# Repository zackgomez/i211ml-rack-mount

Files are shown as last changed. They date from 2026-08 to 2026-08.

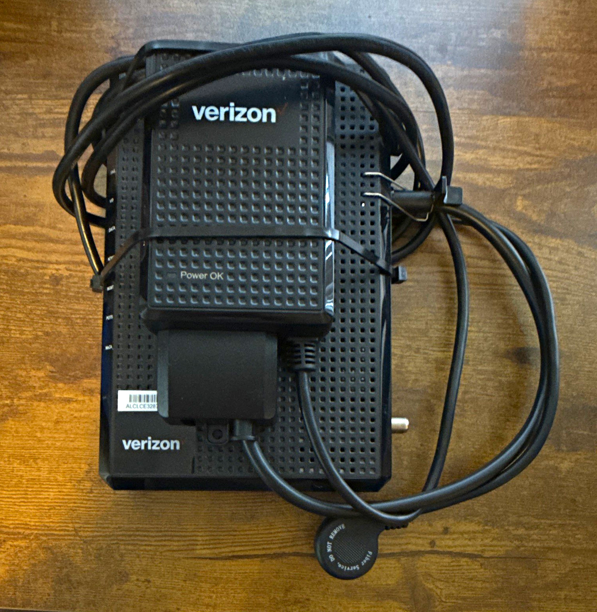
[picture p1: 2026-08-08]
references/ebay-power-brick.jpg

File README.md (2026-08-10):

# Verizon ONT I-211M-L — 19" Rack Mount

**Published**: https://www.printables.com/model/1806857-verizon-fios-i-211m-l-ont-power-brick-19-rack-moun
(CC BY 4.0). Installed and in service 2026-08-10 — ONT in the rack, on the UPS.

Design and print a 1U (or 2U) rack mount for the Verizon FiOS ONT (Alcatel-Lucent
I-211M-L) plus its inline power brick, so the ONT moves from the basement wall box
into the server rack. Fiber arrives as a stiff black drop, coiled/anchored in the
wall box's back pocket, terminating in a green SC/APC connector that plugs into the
ONT — so the move is unplug → re-route a couple feet → replug (or a longer G.657
SC/APC simplex patch cable if slack runs short).

## Device facts

Measured 2026-08-08 with soft tape (±2 mm) except items marked *calipers*.
The Alcatel manual claims 249 × 159 × 38 — trust the tape+calipers numbers below.

**ONT — Alcatel-Lucent I-211M-L** (P/N 3FE52343AKAA, our unit SN ALCLF4493816)
- 227 (x, tape) × 148 (y, *calipers*) × 33 mm (z, *calipers*)
- 45° chamfer on ALL edges, face width 10.5 mm (*calipers*) → ~7.4 mm legs;
  the LED bevel is one of them
- 4 rubber feet on the bottom, Ø11 × 3 tall (*calipers*): gaps measured from
  the chamfer edge, applying on both axes from each corner — LED-side pair
  1.5, port-side pair 20 (centers 14.4 / 32.9 from their corners). Also
  unmeasured mounting bosses, shorter than the feet — the cage floats the
  ONT on its feet so bosses hover
- Rear-face ports, z-centered on the connector face (*calipers*): coax F
  center 36 from the −x face; green SC/APC fiber plug outer edge 20 from the
  +x face (so the fiber lives near the outer wall's rear exit gap)
- Power input: 12 VDC / 2.5 A, keyed circular connector ("TELECOM EQUIPMENT DO NOT
  UNPLUG" collar), max draw 10.5 W — heat is a non-issue, token venting suffices

**Power brick — Verizon "Power OK" inline PSU**
- Body 124 (x) × 85 (y, max) × 44 mm (z) — *calipers*. The y sides are
  drafted, widest at the mid-height shell seam: 83.4 at the bottom face,
  85.0 at the seam, back in toward the chamfer edge (assumed 83.4 via a
  symmetric draft — TODO calipers)
- 6 mm chamfer around the top-face perimeter; vertical edges lightly rounded
  (~r2.5, eyeball); bottom face edges sharp
- Mounting tabs (wall-box rail hooks), bottom-flush, outer vertical corners
  moderately rounded (~r2.5). Wedge profile: max height at the root, sloping
  down to a flat run at min height ending at the tip:
  - body −x end (*calipers*): 18.2 x × 20.3 y, NOT centered — 24.4 off the
    bottom face's −y edge (24.4 + 20.3 + 38.7 closes the 83.4 bottom width
    exactly); wedge 3.8 → 8.2 mm, 4 mm flat
  - far (+x) END of the cord hump: 11 x × 12.5 y, centered on the shroud;
    wedge 3.3 → 7.0 mm, 3 mm flat
- Cord shroud on the +x end (strain relief locking the output cord): 38 beyond
  the body in x, 53 wide in y, bottom-flush, 6 mm margin (*calipers*) off the
  widest −y edge. Side profile: flat top 14 below the brick top (tape), knee
  curving down to a 22.3 mm tip face (*calipers*; traced 2026-08-08, photo in
  Scan inbox). TWO cords (both Ø6, *calipers*) exit the +x end:
  - body cord: leaves the body face toward +y (exact y pending calipers)
    through a strain relief stacked in +x — rect slab 2.5 × 15 × 15, then
    cylinder Ø15 × 12.5 — whose top sits at half the brick height (22), cord
    centerline z ≈ 14.5
  - output cord: off the shroud tip, −y side of the +x tab, cord top 4.8
    below the tip face's max z (centerline z ≈ 14.5 — matches the body cord)
  A half-spool greeble — an unpopulated cord exit ("cord hat") — sits +y of
  the tab on the tip face, its y/z mirroring the output cord across the tab
  (all *calipers*): shaft Ø8 × 6.7, lip Ø10 × 2, bore Ø6, cut at the axis
  z-plane — flat below, half-round above. Full x chain
  incl. tabs ≈ 184 mm; the strain relief reaches ≈ 15 further — keep the
  mount's +x face fully open.
- Port edge (one side): coax F, ground screw, 2× RJ11 POTS, 1× RJ45 GigE, power.
  POTS/MoCA unused — only GigE + power + fiber need routing
- Fiber: SC/APC under a hinged cover on the end opposite the coax
- LEDs (PWR BAT FAIL VID DATA NTWK MGMT POTS MoCA) on the beveled long edge —
  keep visible from the rack front
- Back: 3 keyhole slots (two upper, one lower-center) + 4 rubber feet

**Power brick** — Verizon inline PSU ("Power OK" LED on top), large; has a molded
mounting clip/bracket. Measure the actual unit — dims TBD.

- 1U usable height ≈ 44 mm; ONT lying flat is 38 mm → fits 1U, tight. 2U buys
  room for the brick standing on edge and lazier cable routing.
- 19" opening ≈ 450 mm; ONT flat takes 249 mm → ~200 mm left for the brick bay.

## Design direction

Two-piece screwed-together modular mount, same pattern as the UCG-Fiber mount that
already works well in this rack
(`../UCG-Fiber+PSU+19-inch+Modular+Rack+Mount/` — cage + PSU holder + keystone
passthrough with patch cables). The Print3DSteve Etsy design (central cage + two
ear wings, keystone cutout in one wing) confirms the same architecture at 1U.

Orientation (decided): ONT connector edge (coax, POTS, GigE, power, fiber cover)
faces the REAR of the rack — fiber and power dress off the back, out of sight.
LED bevel faces front. Eth handoff = short patch cable from the rear GigE port,
routed inside the mount, to a keystone jack in the front plate.

Ideas to carry over / decide:
- ONT hangs on printed keyhole posts (3 slots on its back) instead of a full cage —
  smallest modeling job, LEDs stay visible
- Keystone cutout in the front plate (one wing), patch cable inside the mount
- Brick pocket + zip-tie anchors; the brick's own clip may snap onto a printed rail
- Fiber: generous bend radius everywhere (≥30 mm) coming off the rear

## cad/

OpenSCAD, parametric. Shared design language across both mounts:
`wall` / `panel_t` / `shelf_t` = 4 — deliberately kept at 4 (each knob's
4→3 saves only ~8–14 cm³ and spends stiffness exactly at the load
paths: eave retention flex, rack-face flatness, zip-anchor webs).
`devices.scad` = reference solids of ONT + brick (fillet /
chamfer params still TODO-measure). `gauges.scad` = printable go/no-go gauges;
pre-rendered STLs in `cad/stl/`:

- `gauge-ont-cap.stl` — C-channel, slips over the ONT end, checks 148 × 33
- `gauge-ont-length.stl` — U-bar over the 227 length
- `gauge-brick-cap.stl` — C-channel over the brick end, checks 88 × 44
- `gauge-brick-length.stl` — U-bar over the 128 length

All gauges carry 0.5 mm/side clearance (`clear` in gauges.scad). Print flat face
down, no supports. Re-export:
`openscad -D 'part="ont_cap"' -o stl/gauge-ont-cap.stl gauges.scad`

Mount STL + preview regeneration (from `cad/`):

```
openscad --export-format=asciistl -o stl/mount-left-1u.stl mount-left.scad
openscad --export-format=asciistl -D 'panel_u=2' -o stl/mount-left-2u.stl mount-left.scad
openscad --export-format=asciistl -o stl/mount-right-1u.stl mount.scad
openscad -o mount-left-preview.png --imgsize=1600,1100 --viewall --autocenter \
    --camera=0,0,0,65,0,150,0 mount-left.scad   # -preview-rear.png: rz 150->30;
                                                # -2u-preview: add -D 'panel_u=2';
                                                # mount-right-render.png: same
                                                # camera on mount.scad
```

**ASA shrink protocol**: print gauges at 100%, in ASA, same profile as the final
mount. Fit = measurement + shrink verified together; snug/no-go = measure the gap
and adjust `clear` / final pocket clearances. Target for device bays in the real
mount: ~1.5–2 mm/side (tape error + shrink + easy insertion).

Rack-width shrink note: 0.5 % over the 465.1 mm ear-hole span is ~2.3 mm — the
center-cage + two-wings + slotted joints architecture absorbs this; never print
the full 19" width as one piece.

## mount.scad — right half (ONT cage)

UCG-Fiber-style module, panel printed flat on the bed, no supports; 1U
primary (`panel_u`, 2 still renders). Test print v1 (2026-08-08, 1U,
fast ASA): bay width spot-on (227 device / 230 bay confirmed), eave
friction at +0.2 squeeze overly tight → now −0.1 (clearance);
`eave_squeeze` is the tuning knob. Geometry is authored as a left and
mirrored via `right_half = true` so the cage sits rack-RIGHT. The ONT
rides on its feet (solid pads in the hex field, bosses hover); retention
= side eaves + front brow hugging the chamfered edges, brick-cage style:
both side walls run the full bay depth (the inner one continues 4 thick
past the flange) with full-length eaves and the low eave-derived ceiling
(`wall_top = eave_y + eave_depth + 3`; the flange keeps full panel
height for the joint, the brow is panel-face material). The rear is
fully open — fiber, coax, and cords all dress off the back. Each wall
carries the same rounded elongated-hex windows as the brick cage (outer
wall two, inner wall one behind the solid joint span, z-aligned so the
cutouts read through the cage). Joint hardware: M5×16 button heads,
inset Ø10.8 × 3 into the flange's bay-side face (ISO 7380 head 9.5 ×
2.75 vs 1.5 bay clearance), nuts in the left piece's hex pockets.
Roundings match mount-left: panel outer corners r4, cage top-rear r8,
wall edges r2, flange top-rear r6, shelf rear r6.

## mount-left.scad — left half (brick enclosure)

217.6 wide, authored directly as a left; 1U primary (`panel_u`, 2 still
renders — see the variant paragraph below for how the 44-tall brick fits
a 1U panel). The brick lies flat on a hex-vented shelf, long axis along
rack DEPTH:
wall-box tab end forward, cord/shroud end out the fully open rear (both
cords + strain relief dress off the back). The bay sits OUTBOARD, just
inboard of the rack ear, so the brick's weight hangs next to the mounting
hardware — the cage stops 30 from the panel edge (the UCG mount runs 23
and clears this rack's posts; `ear_clear`). The floor plane spans only
the cage. The brick slides in from the rear: side eaves grab the 6 mm
top-perimeter chamfer (same `eave_squeeze` knob, −0.1), a front brow
grabs the front-top chamfer, and the −x tab passes through a slot in the
front wall — its tip rides to 2 from the panel FRONT face (the slot
pockets into the panel's back, keeping the front wall thin) — with a
hold-down bar riding 0.5 over its flat tip. Two
zip-tie slots behind the body anchor the AC cord so tugs land on the
mount, not the brick. Joint flange is 10 thick: M5 holes match mount.scad
(y = panel_h/2, z 20/48); hex nut pockets 8.2 across flats (UCG pockets
measure ~8.1 and press-fit on this printer), 6 deep over a 4 web — an
M5×16 tip lands flush. Two UCG-style gusset ramps brace the flange, one
near each panel edge and inset 6 in y — full 64 depth at the flange, free
edge a concave quarter-circle fillet running out to the panel at x=70.
Rounded corners: panel outer corners r4 (sized to keep the ear-slot web),
cage top-rear r8 across walls + eaves, cage outer edges r2 (wall
top-outer along z, rear verticals), flange rear corners r6 (tangent to
the ramps), shelf rear r6, keystone boss r3. Keystone slot at x = 52
(joint side), y = panel_h/2, face front, latch DOWN, jack in from the
rear: geometry measured off the UCG "Shelf Keystone x6" left module —
no tuned lip; the teeth wedge against tapered clamp faces (hook side
6.35→12.15 over 4.9 deep, latch side 45° 10.15→12.15), 24.3 × 15.0
cavity, and a rear plate whose 19.8 window guides the jack — cut into a
9.5-thick boss on the panel rear. Rack ear ovals 14 × 7 (UCG-style
horizontal play). Low eave-derived ceiling: walls and eaves stop 3 past
the eave slope (the brick's chamfered top stands ~2 proud; the brow's
45° underside runs exactly to the wall top). Material pass: each side
wall carries two elongated-hex windows (45° pointed ends print
bridge-free, corners r4, 8 rib between, rails tied to the
shelf/eave/brick-face/rear-round lines); the front wall is a windowed
frame — three through-pockets behind the panel, two flanking the tab
housing and one over it, keeping the full-perimeter brick stop, the
slot's keying walls + hold-down bar, and the brow foundation.

At 1U — the primary — the 44-tall brick beats the 43.65 panel only by
poaching inter-U slack: the brick tops out exactly at the panel's top
edge (~2.55 under the UCG mount above, whose rear structure starts 1.75
above its own panel edge, measured from its STL), and the floor + walls
hang 4.35 into the U below — empty in this rack — tucked behind the
panel face so nothing shows under the panel from the front. At 1U the
keystone shifts to x = 60 and the gusset runout shortens to x = 44 to
coexist; eaves, brow, tab slot, and joint holes (panel_h/2 pairs with
the right piece at 1U) all re-derive.

## Next steps

1. Caliper the foot center inset from the LED/port edges (est. 8 in
   devices.scad) + body cord y (`cordA_y`)
2. Reprint both pieces at 1U with the material pass + joint insets:
   right verifies eave feel + foot pads + button-head seating; left
   verifies bay/tab/eave fit after the brick-model correction (its test
   v1 2026-08-09: keystone perfect, rack + joint hardware fit well)
3. The physical move (unplug SC/APC, unmount wall box, re-route, replug)

## references/

- `ebay-ont-i211ml-1.jpg` — ¾ view, port edge + vented top
- `ebay-ont-i211ml-2.jpg` — spec label close-up (12VDC 2.5A, P/N, FCC)
- `ebay-ont-i211ml-3.jpg` — port edge straight on (coax, POTS×2, GigE, power, fiber cover)
- `ebay-ont-i211ml-4.jpg` — top face angled, LED labels
- `ebay-ont-i211ml-5.jpg` — front face portrait (Frontier branding, LED edge)
- `ebay-ont-i211ml-6.jpg` — back: 3 keyhole slots, feet, label
- `ebay-power-brick.jpg` — Verizon "Power OK" inline PSU strapped to a G-211M-C (brick style reference)
- `etsy-g211mc-*.png` — Print3DSteve 1U mount for the *G-211M-C* (different ONT, same
  architecture: center cage, two ear wings, keystone cutout)

## Links

- eBay ONT listing (photo source): https://www.ebay.com/itm/303900171619
- eBay brick listing (photo source): https://www.ebay.com/itm/358831177634
- Etsy G-211M-C 1U mount ($83, wrong model): https://www.etsy.com/listing/4328277623
- Print3DSteve also made an I-211M-L variant (Etsy, search their shop):
  https://br.pinterest.com/pin/155303888119943946/
- Only free I-211M-L print (Leviton SMC bracket, not rack):
  https://www.printables.com/model/396377 / https://www.thingiverse.com/thing:5145029
- Physical specs source (Alcatel-Lucent 7302 manual p.1042–1043):
  https://www.manualslib.com/manual/1575417/Alcatel-Lucent-7302.html?page=1042

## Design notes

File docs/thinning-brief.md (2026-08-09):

# Thinning brief — material/print-time pass

You are the third instance on this two-piece 19" rack mount (Verizon ONT
I-211M-L + power brick). Both halves are designed, test-printed once, and
fit-verified. Your mission is plastic and print time, in three stages, in
this order:

1. **Brick cage walls** (`cad/mount-left.scad`): hollow out the wall
   centers — big cutouts through the side walls' free spans, with
   aesthetic corner rounding on the interior (cutout) edges. The panel,
   shelf, front wall, flange, ramps, and keystone boss are NOT in scope
   yet. Also queued in this file, Zack-approved: reduce the front
   tab-seat wall to posts (it must keep: the forward stop for the brick
   face, the tab slot's side keying + hold-down bar over the tab's flat
   tip, and the brow's foundation — "wall with big windows" more than
   freestanding pins).
2. **Discussion**: the primary thickness dimension. `wall = 4`,
   `panel_t = 4`, `shelf_t = 4` are shared design language across BOTH
   pieces. Thinning any of them is a cross-piece change — bring options
   and tradeoffs (stiffness, joint meat, print time deltas) to Zack
   in-terminal, and coordinate with the right-piece session before
   changing shared numbers.
3. **ONT portion** (`cad/mount.scad`): same hollowing treatment. This
   file is owned by the coordinator session ("Design 1U enclosure for
   Verizon ONT relocation") — announce intent via SendMessage before
   editing, rebase-pull first, stage explicit paths only.

## Read first

`README.md` (device facts + per-piece design snapshots), then
`cad/mount-left.scad` and `cad/mount.scad` (both heavily commented),
`cad/devices.scad` (reference solids — brick dims corrected 2026-08-09
after test fit). History/context: `docs/left-half-brief.md`.

## Frozen — do not move

- Joint interface: Ø5.3 holes at y = panel_h/2, z 20/48; left flange 10
  (4 web + 6 hex pocket, AF 8.2); right flange 8.
- Retention contact surfaces: eave 45° undersides (`eave_y`,
  `eave_squeeze`), brow, tab slot fit — fit-critical, test-verified.
- Keystone slot geometry (measured off the UCG Shelf Keystone x6,
  print-verified "perfect").
- Rack ear slots 14×7 at 8.75 from the outer edge.
- Both `panel_u` variants of mount-left must keep rendering (2U default,
  1U with the hanging floor); exports are `stl/mount-left-2u.stl`,
  `stl/mount-left-1u.stl`, `stl/mount-right-1u.stl`.

## Constraints and conventions

- Print orientation: panel flat on the bed, everything grows +z, no
  supports. Wall cutouts are per-layer cross-section changes — keep any
  reappearing material 45°-ramped (see the eave restart ramp discussion
  in git history) or make cutouts full z-columns.
- OpenSCAD gotchas already paid for: never mirror() 2D that feeds
  booleans; top-level variable order matters; F5 shows phantom slices on
  subtractions — verify with F6 or STL sections (`projection(cut=true)`
  over an `import()` of the STL works well; there is also a trimesh venv
  pattern in the session logs).
- The right piece is authored as a left and mirrored (`right_half`);
  mount-left is authored directly.
- Commit + push to master as you land things; plain imperative messages,
  Claude co-author footer (see git log). Rebase-pull before pushing;
  stage explicit paths, never `git add -A` (three sessions share this
  tree).
- Zack watches live in OpenSCAD with auto-reload and is hands-on at the
  printer. Propose before building anything you're unsure of; "propose"
  means show, don't apply.

## Open follow-up (optional, fits stage 3)

mount-left now uses the lean eave-derived ceiling
(`wall_top = eave_y + eave_depth + 3`, brow reach tied to it). The right
piece still runs `wall_top = panel_h` ("print stability, fuller capture,
flush"). The same treatment there would save ~7 of full-thickness wall
band at 1U — candidate for stage 3; propose to Zack and coordinate with
the right-piece session.

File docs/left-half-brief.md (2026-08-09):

# Left-half brief — power brick enclosure

You are building the LEFT half of this two-piece 19" rack mount: the pocket
for the Verizon "Power OK" inline PSU. The right half (ONT cage,
`cad/mount.scad`) is designed, test-printed once, and iterating with Zack.
Deliverable: a first pass + design notes — Zack is hands-on at the printer
and will iterate with you. Propose before building anything you're unsure of.

Read first: `README.md`, `cad/devices.scad` (brick() is fully measured),
`cad/mount.scad` (conventions, rack numbers, and the tricks to reuse).

## Fixed decisions

- Two pieces, ASYMMETRIC split: right piece is 265 wide, this piece gets
  **217.6** (482.6 total). Joint carries M5 screws in x through the right
  piece's 6-thick flange (Ø5.3 holes at z 20 and 48, y = panel_h/2); THIS
  piece carries the nut side — hex pockets, like the UCG-Fiber left module
  Zack owns (`~/sync/3d printing/projects/server rack/UCG-Fiber+PSU+19-inch+
  Modular+Rack+Mount/Left side - Hex Nuts/`). Zack wants "more meat" at the
  joint than the right piece currently has — thickening both sides is on the
  table, coordinate via Zack.
- Rack ear on the outer (rack-left) edge: oval slots 10×7 for M6 cage-nut
  screws, centers 8.75 from the outer panel edge, y at 6.35 and
  panel_h − 6.35.
- **2U only** (`panel_u = 2` equivalent): the brick is 44 tall and cannot
  live in 1U. The right half flips to 2U later.
- Print orientation: front panel flat on the bed, everything grows in +z,
  no supports. Retention features work as wall cross-sections (see the
  eave/brow trick in mount.scad).
- Brick orientation: cords/shroud end (+x in devices.scad coords) faces rack
  REAR. Keep that whole face open — two Ø6 cords exit there, plus the strain
  relief reaching ~15 beyond the body face at mid-height. Total x-chain with
  both tabs ≈ 184, lying along the rack WIDTH: fits inside 217.6 minus walls,
  but it's snug — budget carefully.

## Retention ideas (propose, don't gold-plate)

- The brick's top perimeter has a 6 mm chamfer → the mount.scad eave trick
  (45°-parallel underside, `eave_squeeze`) works here too. Note: v1 print
  showed +0.2 squeeze is overly tight in ASA; right half now runs −0.1.
- The −x tab (wedge 3.8→8.2 thick, flat at tip, bottom-flush) faces rack
  FRONT — a printed pocket/rail seat is a natural positive lock.
- The +x tab hangs off the shroud tip at the rear; a narrow centered catch
  clears both cords (they exit ±y of it). Optional.
- Sides bulge ~1.2 mm ("diamond") at mid-height; 124 × 88 are max-envelope
  calipers. Baseline clearance `clr = 1.5` per side like the right half.
- Zack liked capturing the device UCG-style (cage, not straps).

## Open questions for Zack

- Keystone: the original plan puts an ethernet keystone in a front plate
  (patch cable from the ONT's rear GigE port). This panel has the free area —
  propose a keystone cutout location.
- Joint hardware final choice (hex pockets assumed), flange meat.
- Whether the brick pocket needs venting (10.5 W max — probably token).

## OpenSCAD gotchas already paid for

- Never `mirror()` a 2D profile that feeds booleans — CGAL "mesh not closed".
  Build flipped profiles directly (see `_tab_plan(tip_right)`).
- Top-level variable order matters: define before use.
- Preview (F5) shows phantom slices on subtractions — verify with F6 or a
  `projection(cut=true)` bbox check before believing a "bug".
- Ghost-device pattern: `%` + `show_*` flag + `$preview` (see assembly() in
  mount.scad); ghosts stay out of renders/STLs.
- Right half is authored as a left and mirrored at top level
  (`right_half = true`) — author THIS piece directly as a left (no mirror).

## Workflow

- Files: `cad/mount-left.scad`. If you extract shared rack numbers into a
  common include, keep `mount.scad` rendering identically (verify before
  commit).
- Render preview PNGs into `cad/`, export `cad/stl/mount-left-2u.stl`.
- Commit + push to master as you land things; plain imperative messages,
  end with the Claude co-author footer (see git log).
- OpenSCAD is installed; Zack views live with auto-reload. `present
  <file>` opens files on his desktop.

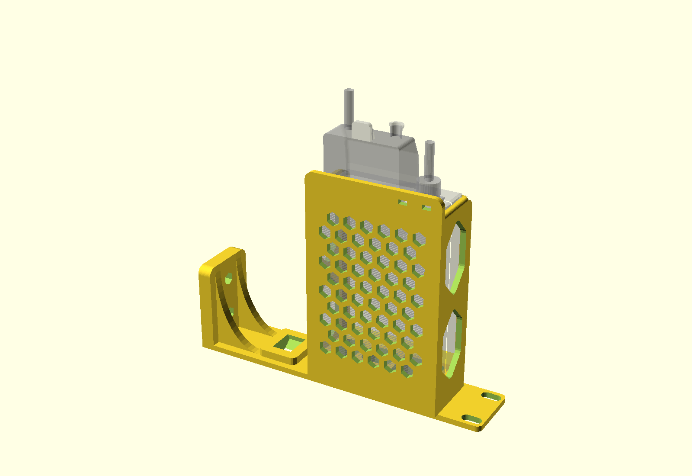
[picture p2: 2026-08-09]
cad/mount-left-preview-rear.png

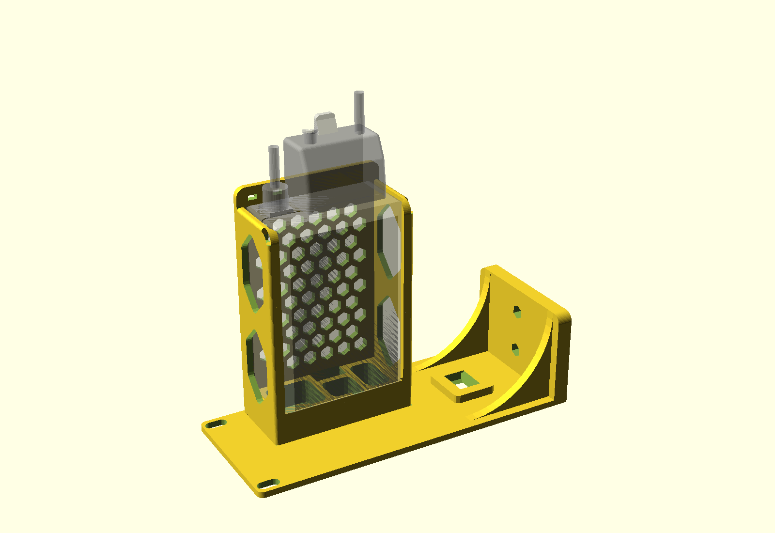
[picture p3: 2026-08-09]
cad/mount-left-2u-preview.png

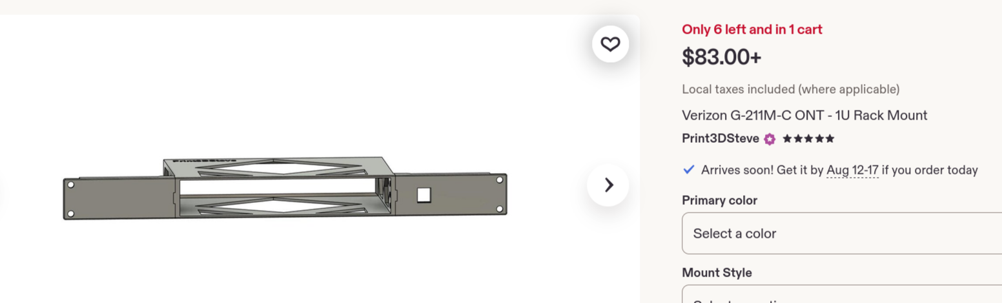
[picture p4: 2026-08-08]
references/etsy-g211mc-listing-page.png

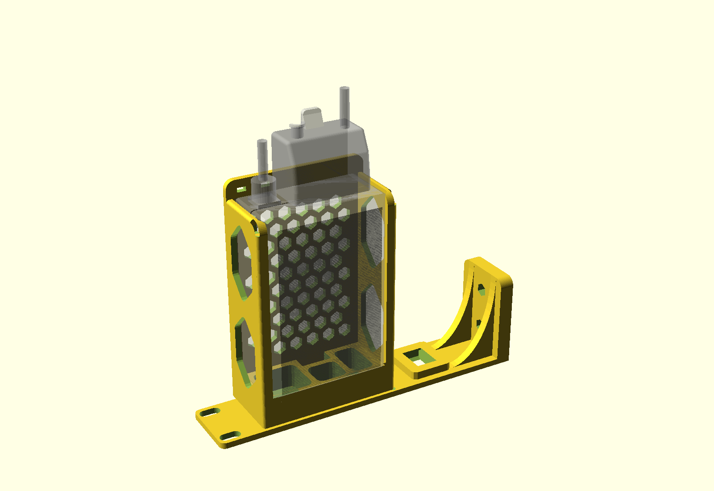
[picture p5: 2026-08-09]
cad/mount-left-preview.png

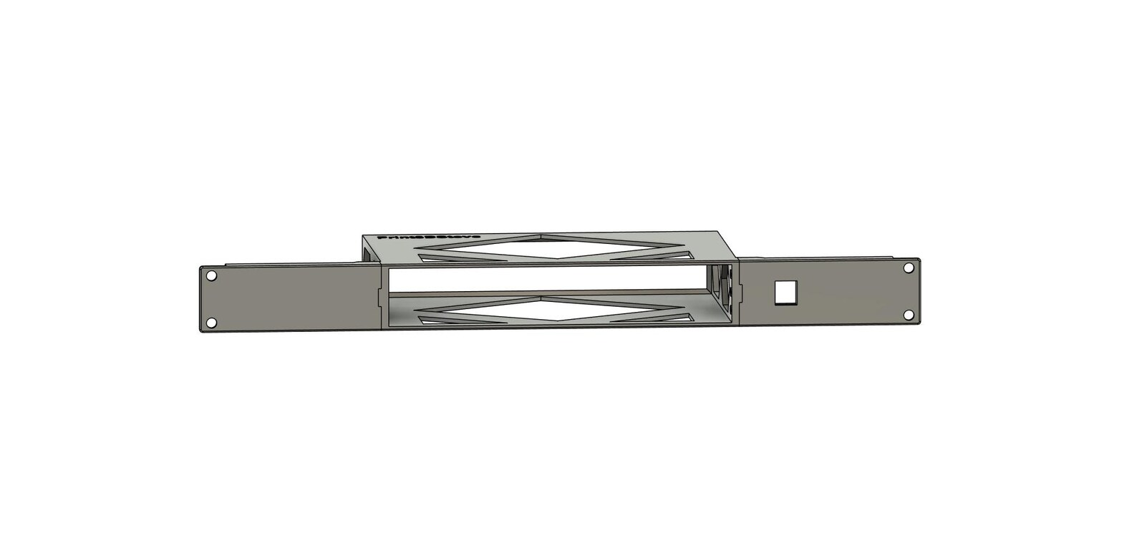
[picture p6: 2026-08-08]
references/etsy-g211mc-mount-front.png

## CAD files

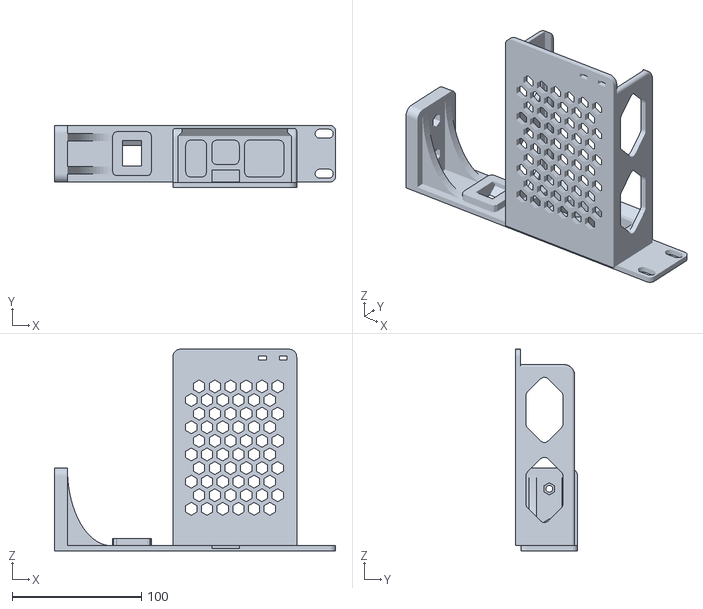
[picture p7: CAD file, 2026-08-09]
cad/stl/mount-left-1u.stl
217.6 x 48.0 x 156.2

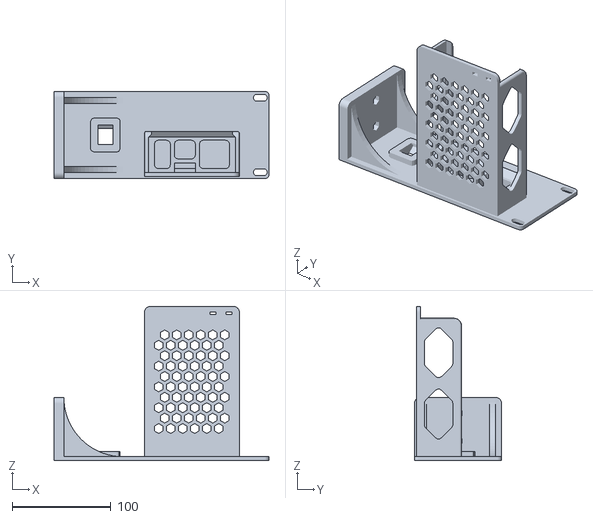
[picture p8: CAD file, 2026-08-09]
cad/stl/mount-left-2u.stl
217.6 x 88.1 x 156.2

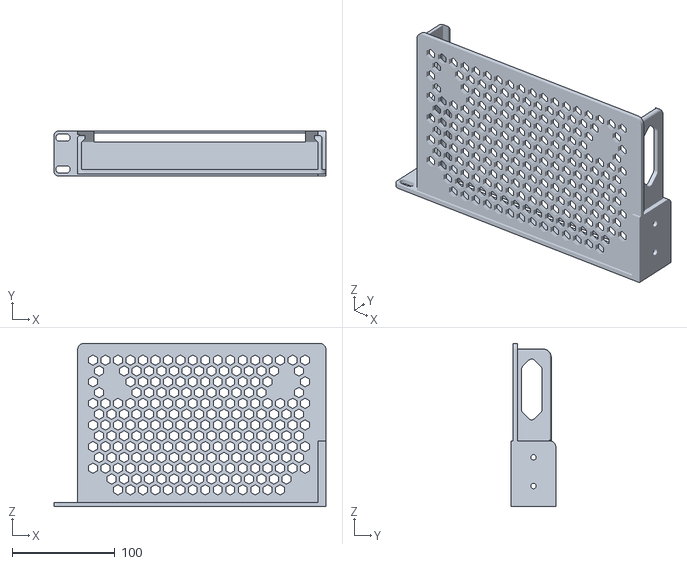
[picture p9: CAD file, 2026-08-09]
cad/stl/mount-right-1u.stl
265.0 x 43.6 x 159.0

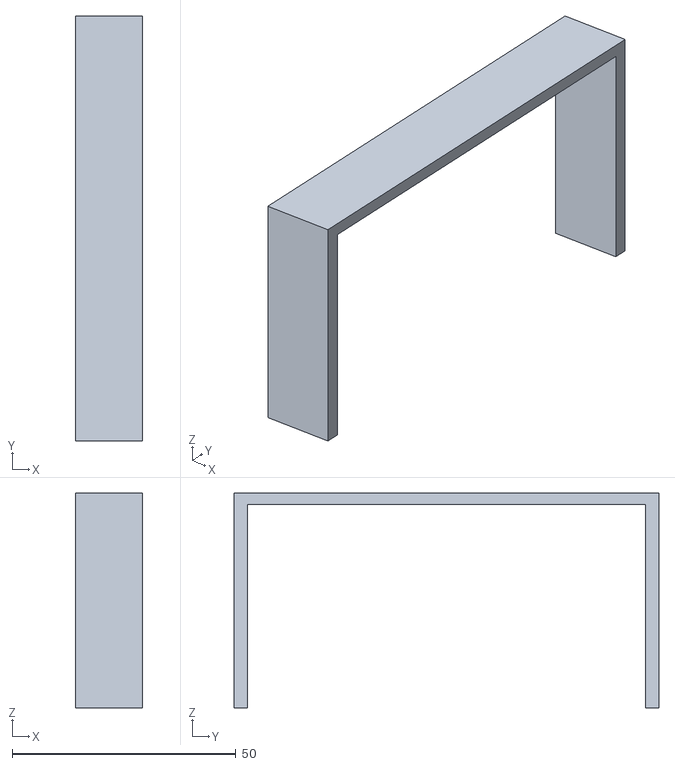
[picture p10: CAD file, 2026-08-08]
cad/stl/gauge-brick-cap.stl
15.0 x 95.0 x 48.0

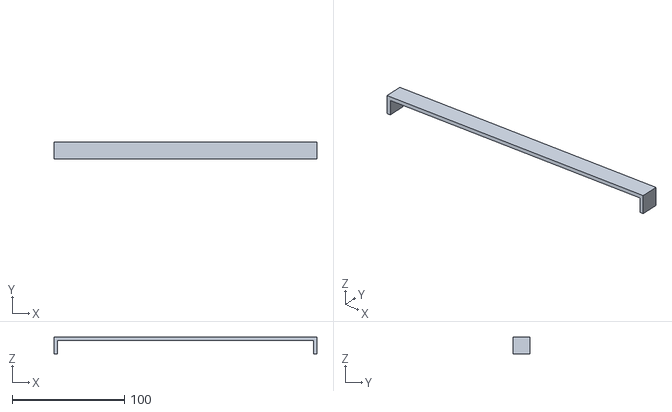
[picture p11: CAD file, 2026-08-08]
cad/stl/gauge-ont-length.stl
234.0 x 15.0 x 15.0

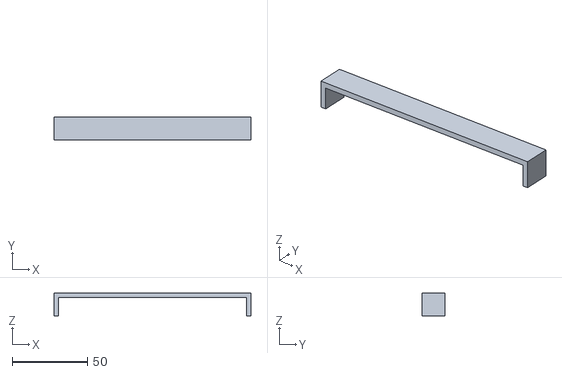
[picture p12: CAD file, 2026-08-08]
cad/stl/gauge-brick-length.stl
131.0 x 15.0 x 15.0

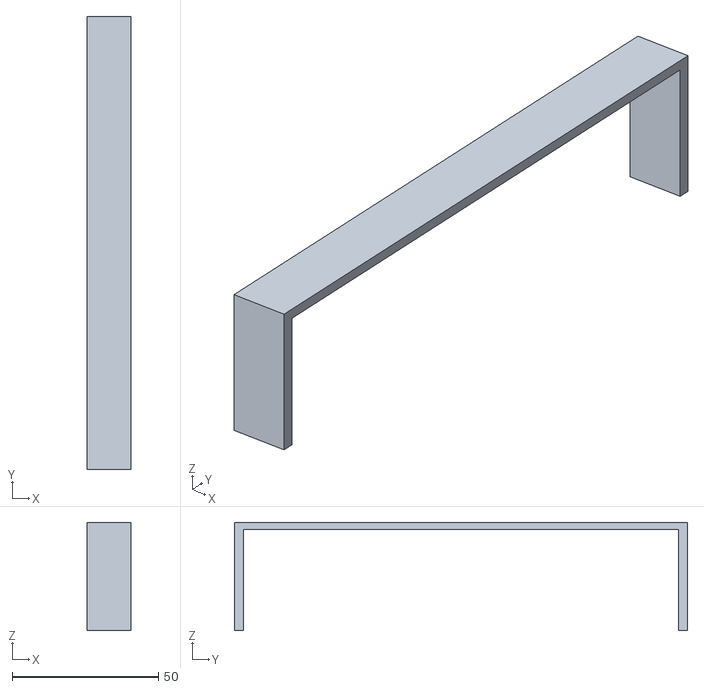
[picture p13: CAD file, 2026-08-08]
cad/stl/gauge-ont-cap.stl
15.0 x 155.0 x 37.0

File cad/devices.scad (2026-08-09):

// Verizon I-211M-L ONT + inline power brick — reference solids
// All primary dims calipers, 2026-08-08.
// Axes: x = along the rack face, y = depth, z = up; devices lying flat.
// Origin: bottom-left-front corner of each body's bounding box.

// Octagonal profile: w x h rectangle with corners cut c.
// bottom=false leaves the two bottom corners sharp.
function _prof(w, h, c, bottom = true) = bottom
    ? [[c, 0], [w - c, 0], [w, c], [w, h - c], [w - c, h], [c, h], [0, h - c], [0, c]]
    : [[0, 0], [w, 0], [w, h - c], [w - c, h], [c, h], [0, h - c]];

// Box with 45-degree chamfer c on edges.
// bottom=false: edges of the bottom face stay sharp (vertical edges still cut).
module chamfered_box(x, y, z, c, bottom = true) {
    intersection() {
        linear_extrude(z)                            // vertical edges
            polygon(_prof(x, y, c));
        translate([0, y, 0]) rotate([90, 0, 0])      // edges running along y
            linear_extrude(y) polygon(_prof(x, z, c, bottom));
        rotate([90, 0, 90])                          // edges running along x
            linear_extrude(x) polygon(_prof(y, z, c, bottom));
    }
}

// ---------------- ONT ----------------
ont_l = 227;          // x, soft tape +-2
ont_w = 148;          // y, calipers
ont_h = 33;           // z, calipers
ont_chamfer_face = 10.5;              // calipers, width of the 45° chamfer FACE,
ont_chamfer = ont_chamfer_face / sqrt(2);  // -> ~7.4 leg; ALL edges incl. LED bevel

// Connector edge = one long (x) edge -> faces rack rear.
// LED bevel = opposite long edge -> faces rack front (model y = ont_w edge).

// Rubber feet on the bottom face (calipers except inset depth). There are
// also mounting bosses on the bottom, shorter than the feet — unmeasured;
// the ONT rides on its feet so bosses just need to hover.
foot_d = 11;
foot_h = 3;
// Foot gaps are measured from the CHAMFER edge (where the corner cut meets
// the side), and each pair's gap applies on BOTH axes from its corner.
foot_gap_led = 1.5;    // LED-side pair
foot_gap_port = 20;    // port-side pair
f_led  = ont_chamfer + foot_gap_led  + foot_d / 2;   // center from corner
f_port = ont_chamfer + foot_gap_port + foot_d / 2;

ont_feet = [
    [f_led,          ont_w - f_led],
    [ont_l - f_led,  ont_w - f_led],
    [f_port,         f_port],
    [ont_l - f_port, f_port],
];

// Rear-face ports, centered in z on the connector face (y=0). Positions
// calipers; stub sizes estimated. Modeled as protruding stubs so mount
// keep-outs and cable sweep are visible on the ghost.
coax_x = 36;                 // F-connector center to the -x face
coax_d = 9.5;
coax_len = 12;
fiber_edge_x = ont_l - 20;   // green SC/APC plug outer edge to the +x face
fiber_w = 9.4;
fiber_h = 9;
fiber_len = 30;              // connector body + start of boot

module ont() {
    chamfered_box(ont_l, ont_w, ont_h, ont_chamfer);
    for (p = ont_feet)
        translate([p[0], p[1], -foot_h])
            cylinder(h = foot_h + 0.5, d = foot_d, $fn = 24);
    // port stubs on the connector face
    translate([coax_x, 0.5, ont_h / 2]) rotate([90, 0, 0])
        cylinder(h = coax_len + 0.5, d = coax_d, $fn = 24);
    translate([fiber_edge_x - fiber_w, -fiber_len, (ont_h - fiber_h) / 2])
        cube([fiber_w, fiber_len + 0.5, fiber_h]);
}

// ---------------- Power brick ----------------
// Calipers except where noted. Envelope quirk: sides bow out ("diamond") —
// widest ~1.2 mm proud of the chamfer edge at mid-height (rough measurement).
// 124 x 88 are max-envelope caliper numbers, so pockets sized off these are
// safe; the body is just a touch slimmer near top and bottom.
brick_l = 124;        // x
brick_w = 85;         // y, max envelope — at the mid-height shell seam
brick_w_bot = 83.4;   // y at the bottom face (calipers 2026-08-09)
brick_w_top = 83.4;   // y at the chamfer edge — symmetric draft (confirmed
                      // by eye 2026-08-09, not calipered)
brick_h = 44;         // z
brick_chamfer = 6;    // top-face perimeter only
brick_corner_r = 2.5; // vertical edges "lightly rounded" — eyeball value
byi = (brick_w - brick_w_bot) / 2;   // bottom inset per side
tyi = (brick_w - brick_w_top) / 2;   // chamfer-edge inset per side

// shell parting line: groove around the body at the z-center plane where the
// two plastic shell halves mate
seam_h = 1;           // z height of the groove
seam_d = 1;           // how deep it cuts into the x/y faces

// Mounting tabs on BOTH x ends: bottom-flush wedges, thick at the body,
// sloping down to a FLAT RUN at min height out to the tip. The two tabs
// differ in plan AND position (calipers 2026-08-09): the -x body tab is
// the big one, offset toward -y (24.4 off the bottom face's -y edge, and
// 24.4 + 20.3 + 38.7 closes the 83.4 bottom width exactly); the +x tab
// on the shroud tip is the small centered one.
tabm_len = 18.2;  tabm_w = 20.3;                       // -x tab plan
tabm_y = byi + 24.4;                                   // its -y edge, bbox frame
tabm_h_min = 3.8;  tabm_h_max = 8.2;  tabm_flat = 4;   // -x tab wedge
tab_len = 11;         // +x tab, x
tab_w = 12.5;         // +x tab, y
tab_r = 2.5;          // outer vertical edges "moderately rounded" — eyeball
tabp_h_min = 3.3;  tabp_h_max = 7.0;  tabp_flat = 3;   // +x tab wedge

// plan footprint of a tab, tip corners rounded; tip at x=0, or at x=len
// with tip_right=true (built directly, not mirror()ed — mirrored 2D reverses
// winding and CGAL rejects the extruded intersection as non-closed)
module _tab_plan(len, w, tip_right = false) {
    cx = tip_right ? len - tab_r : tab_r;
    hull() {
        translate([tip_right ? 0 : len - 1, 0]) square([1, w]);
        translate([cx, tab_r]) circle(tab_r, $fn = 32);
        translate([cx, w - tab_r]) circle(tab_r, $fn = 32);
    }
}

// Cord-exit protrusion on the +x end (soft tape). Modeled as its full
// envelope box — the taper is ignored on purpose, pockets must clear it anyway.
// ---- cord shroud (+x end) ----
// TWO cords exit the +x end (stub cylinders below — leave the whole +x face
// open in the mount):
//   1. body cord, toward the +y edge of the body's +x face
//   2. output cord, locked in by the cord shroud (strain relief), leaving the
//      shroud's tip face on the -y side of the +x tab
// The +x tab hangs off the FAR (+x) END of the shroud, bottom-flush, centered
// on the shroud's y span. A small cylindrical greeble sits on the +y side of
// the tab on the same face.
shroud_len = 38;      // x beyond the body
shroud_y0 = 6;        // margin from the -y edge (calipers)
shroud_w = 53;        // y
shroud_drop = 14;     // its flat top sits this far below the brick top
shroud_h_tip = 22.3;  // height of the tip face (calipers)
shroud_h_root = brick_h - shroud_drop;
shroud_r = 2.5;       // all edges moderately rounded EXCEPT the floor
tabp_y = shroud_y0 + (shroud_w - tab_w) / 2;   // +x tab centered on the shroud

// Cords Ø6 (calipers). y of the body cord still TODO calipers.
cord_d = 6;
cord_stub = 25;                      // how far bare-cord stubs poke out

// Body cord strain relief: stacked in +x off the body face — rect slab, then
// cylinder, then the cord. Max z extent of the relief = brick_h/2 (calipers).
srA_rect_x = 2.5;                    // slab thickness in x
srA_wh = 15;                         // slab is 15 x 15 in y/z; cylinder Ø15
srA_cyl_len = 12.5;
srA_top = brick_h / 2;               // top of the whole relief stack
cordA_y = brick_w - 10 - cord_d / 2; // TODO calipers — "a bit more -y" than 6
cordA_z = srA_top - srA_wh / 2;      // relief + cord centerline (14.5)

// Shroud cord: top of cord 4.8 (calipers) below the tip face's max z
cordB_y = (shroud_y0 + tabp_y) / 2;  // -y side of the tab
cordB_z = shroud_h_tip - 4.8 - cord_d / 2;

// greeble on the +y side of the tab: an unpopulated cord exit ("cord hat").
// Half-spool, its y and z mirroring the shroud cord across the tab: shaft
// then lip stacked in +x, center drilled out Ø6 (cord-sized), then cut at
// the axis z-plane — flat below, half-round above. All calipers.
greeble_shaft_len = 6.7;  greeble_shaft_d = 8;
greeble_lip_len = 2;      greeble_lip_d = 10;
greeble_y = (tabp_y + tab_w + shroud_y0 + shroud_w) / 2;  // cordB_y mirrored
greeble_z = shroud_h_tip - 4.8 - cord_d / 2;              // = cordB_z
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

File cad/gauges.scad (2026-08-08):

// Printable fit gauges for the I-211M-L rack mount project.
// Slip these over the real devices to validate measurements + ASA shrink
// before cutting the actual mount. Print at 100% — if a gauge is tight,
// the difference IS the number to bake into the final clearances.
//
// Render one part at a time:
//   openscad -D 'part="ont_cap"' -o stl/gauge-ont-cap.stl gauges.scad

include <devices.scad>
show_devices = false;   // suppress the device preview from devices.scad

part = "all";     // ont_cap | ont_length | brick_cap | brick_length | all

clear = 0.5;      // per-side clearance built into every gauge
wall = 3;
lip = 15;         // how far a cap slips onto the device

// C-channel cap that slips over the end of a w x h cross-section.
// Open on one long face (so it clears feet/labels) and at the mouth.
module end_cap(w, h) {
    iw = w + 2 * clear;
    ih = h + 2 * clear;
    difference() {
        cube([lip, iw + 2 * wall, ih + wall]);          // no floor wall: open face
        translate([-1, wall, -1]) cube([lip + 2, iw, ih + 1 + clear]);
    }
}

// U-bar: checks an outside length between two end stops.
module length_gauge(l, stop = 12) {
    il = l + 2 * clear;
    w = 15;
    difference() {
        cube([il + 2 * wall, w, stop + wall]);
        translate([wall, -1, -1]) cube([il, w + 2, stop + 1]);
    }
}

if (part == "ont_cap" || part == "all")
    end_cap(ont_w, ont_h);                              // 148 x 33 cross-section

if (part == "ont_length" || part == "all")
    translate([0, 60, 0]) length_gauge(ont_l);          // 227 outside length

if (part == "brick_cap" || part == "all")
    translate([0, 110, 0]) end_cap(brick_w, brick_h);   // 88 x 44 cross-section

if (part == "brick_length" || part == "all")
    translate([0, 230, 0]) length_gauge(brick_l);       // 128 outside length

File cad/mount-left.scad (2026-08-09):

// mount-left.scad — 19" rack mount, LEFT piece: power-brick enclosure.
// Same family as mount.scad (right piece / ONT cage): front panel printed
// flat on the bed, shelf + walls growing in +z, mating flange on the inner
// edge, rack ear on the outer edge. No supports. Authored directly as a
// left — no top-level mirror.
//
// Model axes == print axes (same as mount.scad):
//   x = rack width, 0 at the joint (mating) edge, +x toward the rack ear
//   y = rack vertical, 0 at the panel bottom edge
//   z = rack depth, 0 at the panel front face (the build plate)
//
// Brick orientation: devices.scad -x end (body tab) faces the rack FRONT,
// the cord/shroud end faces the rack REAR — both cords and the strain
// relief hang out the open rear. devices y spans rack width with the
// shroud side toward the joint, so the output cord exits next to the ONT
// half; devices z is rack-vertical. The brick slides in from the rear.
// The bay sits OUTBOARD (against the rack ear) so the brick's weight is
// close to the mounting hardware; the keystone takes the joint side.

include <devices.scad>
show_devices = false;

show_brick = true;      // ghost brick in preview (F5) only; not in render/STL

// ---- rack geometry (keep in sync with mount.scad) ----
panel_u = 1;            // 1U primary — the 44-tall brick pokes into the
                        // empty U below (see shelf_y0); 2 still renders
u_pitch = 44.45;
panel_h = panel_u * u_pitch - 0.8;
panel_t = 4;
rack_total_w = 482.6;
hole_span = 465.1;
edge_to_hole = (rack_total_w - hole_span) / 2;   // 8.75
right_piece_w = 265;                     // = mount.scad piece_w
piece_w = rack_total_w - right_piece_w;  // 217.6
slot_x = piece_w - edge_to_hole;         // rack slot center, from the joint edge

rack_slot_w = 14;       // oval slots for M6 cage-nut screws; wide like the
rack_slot_h = 7;        // UCG mount's 13 x 6.5 — horizontal play absorbs
                        // rack tolerance + ASA shrink over the panel width

// ---- joint: this piece carries the nuts ----
// M5 screws come through the right piece's 6-thick flange; hex pockets here
// hold the nuts, UCG-Fiber left-module style. Hole y/z MUST match mount.scad
// (y = panel_h/2, z = 20 and mate_z1 - 16 = 48).
mate_hole_d = 5.3;
mate_hole_z = [20, 48];
flange_t = 10;          // "more meat" than the right piece's 6
flange_z1 = 64;         // = mount.scad mate_z1
nut_af = 8.2;           // M5 nut is 8.0 across flats; the UCG mount's pockets
                        // measure ~8.1 and press-fit on this printer (in-plane
                        // holes print ~0.2 under) — tune here if loose/tight
nut_pocket_t = 6;       // pocket depth; the 4-thick web puts an M5x16 tip
                        // flush with the flange's inner face

// Joint ramps: UCG-style gussets bracing the flange to the panel, one near
// each panel edge, inset in y. Full flange depth at the flange; the free
// edge is a concave quarter-circle fillet running out to the panel — a
// little over half the plastic of the straight-hypotenuse triangle.
ramp_t = 6;
ramp_x1 = panel_u == 1 ? 44 : 70;  // shorter runout at 1U clears the
                                   // keystone boss (which shifts to x=60)
ramp_inset = 6;

// corner-rounding pass
panel_r = 4;            // panel's outer corners (small enough to keep the
                        // web at the ear slots' outer ends)
cage_r = 8;             // cage top-rear corner, across walls + eaves
cage_er = 2;            // cage outer edges: wall top-outer (along z) and
                        // rear vertical (along y)
flange_r = 6;           // flange rear corners (= ramp_inset, so the cuts
                        // land tangent to the ramps)
shelf_r = 6;            // shelf rear corners
boss_r = 3;             // keystone boss

// ---- cage ----
clr = 1.5;              // pocket clearance per side (matches right piece)
wall = 4;
// 1U: the brick (44) is taller than a 1U panel (43.65) — it fits only by
// poaching the inter-U slack. The brick tops out exactly at the panel's
// top edge — 2.55 under the UCG mount above, whose rear structure starts
// 1.75 above its own panel edge — and the floor + walls hang 4.35 into
// the empty U below, tucked behind the panel face (z >= panel_t) so
// nothing shows under the panel from the front.
shelf_t = 4;
shelf_y0 = panel_u == 1 ? panel_h - shelf_t - brick_h : 2;
shelf_top = shelf_y0 + shelf_t;
wall_y0 = panel_u == 1 ? shelf_top : shelf_y0;
struct_z0 = panel_u == 1 ? panel_t : 0;   // sub-panel structure stays hidden

// The cage sits just inboard of the rack ear: the UCG mount's structure
// stops 22.9 from the panel edge and clears the rack post in this rack, so
// 23 is the proven minimum — 30 buys a little extra room at the post.
ear_clear = 30;
bay_w = brick_w + 2 * clr;
cage_x1 = piece_w - ear_clear;
bay_x1 = cage_x1 - wall;
bay_x0 = bay_x1 - bay_w;

// depth chain: panel, front wall (tab seat), body, open rear. The tab tip
// rides to 2 from the panel FRONT face — its slot pockets into the panel's
// back, leaving a 2 web — which keeps the front wall thin.
tab_tip_z = 2;
body_z0 = tab_tip_z + tabm_len;    // brick body front face
body_z1 = body_z0 + brick_l;
wall_z1 = body_z1;                 // walls + eaves stop at the body rear face
shelf_z1 = body_z1 + 12;           // shelf runs on under the shroud root

brick_top = shelf_top + brick_h;

// ---- retention ----
// Side eaves over the brick's 6 mm top-perimeter chamfer: same 45°-parallel
// underside and tuning knob as the right piece. The drafted sides put the
// chamfer edge (brick_w_top) inboard of the max envelope — the eave drops
// by that inset to keep the same engagement.
eave_depth = 3;
eave_squeeze = -0.1;    // +interference / -clearance against the chamfer face
eave_y = brick_top - brick_chamfer - clr - eave_squeeze
         - (brick_w - brick_w_top) / 2;
// Low ceiling: walls/eaves stop 3 past the eave slope — all the capture is
// in the chamfer grab. The brick's chamfered top stands ~2 proud of the
// walls; the brow runs exactly to the wall top (its 45° underside still
// spans the whole front chamfer face).
wall_top = min(eave_y + eave_depth + 3, panel_h);

// The front wall doubles as the tab seat: the -x wall-box tab (the big
// offset one) passes through a slot to 2 short of the panel front, and a
// bar over the tab's 4 mm flat tip holds the nose down.
slot_fit = 0.5;                        // per side around the tab
tab_slot_x0 = bay_x0 + clr + tabm_y - slot_fit;
tab_slot_w = tabm_w + 2 * slot_fit;
bar_z1 = tab_tip_z + tabm_flat;        // bar covers the flat run at the tip
bar_y = shelf_top + tabm_h_min + 0.5;  // bar underside just over the flat tip
slot_y1 = shelf_top + tabm_h_max + 1.5;

// Front brow over the brick's front-top chamfer (right piece's brow trick).
// Full bay width — nothing to see on the brick's front face. Its reach is
// tied to the wall top: the brow's 45° underside ends where the wall does.
brow_z1 = body_z0 + (wall_top - eave_y);

// ---- wall hollowing ----
// The side walls' free spans (between shelf, eave zone, front wall, and
// rear edge) carry no load worth 4 mm of solid — cut windows. Elongated
// hexagons: the 45° ends grow and close printably in the walls' per-layer
// cross-section (no flat bridges — just a ~6 chord at each rounded tip)
// and echo the shelf's hex vents. One rib splits each wall's span.
win_r = 4;                  // corner rounding, all cutout edges
win_y0 = shelf_top + 4;     // rail above the shelf junction
win_y1 = eave_y - 3;        // rail below the eave slope
swin_z0 = body_z0;          // window tips align with the brick's front face
swin_z1 = wall_z1 - 8;      // rear rail, sized with the r8 corner round
swin_rib = 8;
swin_w = (swin_z1 - swin_z0 - swin_rib) / 2;
// The front wall keeps its full-perimeter frame (its rear face is still
// the brick's forward stop all the way around), the tab slot's keying
// walls + hold-down bar, and the brow's foundation — two through-pockets
// behind the panel flank the tab housing: a wall with big windows.
fwin_x = [[bay_x0 + 6, tab_slot_x0 - 4],
          [tab_slot_x0 + tab_slot_w + 4, bay_x1 - 6]];
// third pocket, over the tab housing: the slot's keying walls and the
// hold-down bar all live below slot_y1 — the column above is free
fwin3_y0 = slot_y1 + 4;
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

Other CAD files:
cad/mount.scad

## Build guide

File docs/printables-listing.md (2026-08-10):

# Printables upload package

Everything below is paste-ready. Files to upload are listed at the bottom.

## Title

Verizon FiOS I-211M-L ONT + Power Brick — 19" Rack Mount (1U, two-piece)

## Category / tags

Category: Gadgets → Computers (or Hobby & Makers → Organizers)
Tags: `rack-mount`, `19-inch`, `1u`, `verizon`, `fios`, `ont`, `i-211m-l`,
`homelab`, `server-rack`, `network`, `openscad`, `asa`

## Summary (120-char limit)

Two-piece 1U rack mount for the Verizon FiOS I-211M-L ONT and its power
brick — LED window, keystone, tool-free fit.

## Description

Moves the Verizon FiOS I-211M-L ONT and its "Power OK" power brick out of
the wall box and into a 19" rack: a two-piece 1U mount with a status-LED
window, keystone passthrough for the ethernet handoff, and tool-free
friction retention that hugs the devices' chamfered edges — no straps,
no screws touching the devices.

Two modules that bolt together into one 19" × 1U face:

- **Right piece — ONT cage.** Hex-vented shelf, side eaves and a front brow
  whose 45° undersides ride the ONT's chamfered edges: slide it in from the
  rear and it self-centers with a light friction grip. The ONT rides on its
  own rubber feet (solid landing pads in the vent field). Status LEDs show
  through a front window; the fiber exits through a gap in the outer wall
  with gentle bend radius; all copper dresses off the open rear.
- **Left piece — power brick cage.** The brick slides in tab-first; its own
  wall-box mounting tab locks under a hold-down bar, eaves grab the top
  chamfer, both cords exit the open rear. Keystone slot in the front face
  for the ethernet handoff (short patch cable inside, rack patching outside).
- Pieces join with two M5 screws into captive hex nuts; each ear takes
  standard M6 cage-nut hardware with widened slots for alignment play.

**1U height note:** the brick is 44 mm tall — this mount lets it dip a few
mm into the rack unit BELOW the panel, so that U must be empty (or use the
included 2U left piece, which keeps everything inside its own footprint —
it pairs with the same right piece printed unchanged; joint holes align at
either height from the source).

Printed in ASA and living in my rack (photos). OpenSCAD source, full
device measurements, and the design/build log:
https://github.com/zackgomez/i211ml-rack-mount

Designed in collaboration with Claude (Fable 5) — co-authored per the
repo's git history.

*This is a fan-made mount; not affiliated with Verizon. The ONT remains
your ISP's property — relocate gently, mind the fiber bend radius, and
keep the dust caps on anything you unplug.*

## Print settings

- Orientation: front panel flat on the bed (as exported)
- Supports: none — EXCEPT `mount-left-1u.stl`, which needs a small support
  under the below-panel overlap (the few mm that dip into the U beneath).
  The 2U left piece and the right piece print support-free
- As printed (the units in the photos): Polymaker ASA, 0.6 mm nozzle,
  0.4 mm layers, 2 walls, 15 % infill
- Bed: the right piece is 265 mm wide — printed diagonally on a 250 mm
  Voron (just fits); 300 mm beds take it straight

## Assembly / hardware

- 2× M5×16 + 2× M5 hex nuts (nuts press into the left piece's pockets)
- 4× M6 cage nuts + screws (or your rack's 10-32/12-24 hardware)
- 1× RJ45 keystone jack + short patch cable (ONT GigE → keystone)
- Load the ONT: slide in from the rear until the front brow grips
- Load the brick: slide in tab-first until the tab seats under the bar
- Friction fit tuning: `eave_squeeze` in the OpenSCAD source

## Files to upload

STLs (from `cad/stl/`):
- `mount-right-1u.stl` — ONT cage, right half
- `mount-left-1u.stl`  — brick cage + keystone, left half (dips into the U below)
- `mount-left-2u.stl`  — alternative left half, self-contained 2U

Photos (from `photos/`):
- `installed-front.jpg` — **cover image** (LEDs through the window, in-rack)
- `installed-rear.jpg`  — rear cable dressing
- `bench-assembled.jpg` — both devices loaded, on the bench

Renders (from `cad/`):
- `render-assembly-front.png` — both pieces joined, interior view
- `render-right-iso.png` — ONT cage with ghosted ONT (shows retention)
- `render-left-iso.png`  — brick cage with ghosted brick

License: **CC BY 4.0** — matches "public domain + please credit me";
attribution is the only requirement, commercial use allowed.

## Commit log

2026-08-08 Initial commit: I-211M-L ONT + power brick reference models, fit gauges, project notes
    Measured device solids in OpenSCAD (devices.scad), printable go/no-go
    gauges with STLs, and the README covering measurements, design
    direction (2U, center cage + ear wings), and the ASA shrink protocol.
    [devices.scad, gauge-brick-cap.stl, gauge-brick-length.stl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]
2026-08-08 Add shell parting-line groove to the brick body
    1 x 1 mm ring cut into the x/y faces at the z-center plane, where the
    two halves of the PSU shell mate.
    [devices.scad]
2026-08-08 Right-half ONT cage v1 (mount.scad, 1U test height)
    UCG-Fiber-style module: front panel printed flat on the bed, hex-vented
    shelf, rear corner posts with top lips, LED window, M6 rack slots, M5
    joint holes in the mating flange. Asymmetric width split (265 / 217.6)
    because the 227 mm ONT does not fit inside a centered half. Outer wall
    stops short of the rear to leave the fiber exit open. panel_u switches
    1U test prints to the final 2U.
    [mount-right-1u.stl, mount.scad]
2026-08-08 Cage v2: replace rear posts with chamfer-hugging top eaves
    Narrow vaulted eaves along both side walls; their 45-degree undersides
    sit parallel to the ONT's top-edge chamfers with 0.2 mm interference —
    slight friction fit, self-centering, ONT slides in from the rear.
    Pure wall cross-section in print orientation, no overhangs.
    [mount-right-1u.stl, mount.scad]
2026-08-08 Cage v3: front brow grabs the ONT's front-top chamfer
    Extra meat on the panel's +y edge extending to z=14, past the chamfer
    face, with the same 45-degree-parallel underside as the side eaves.
    Split into two segments flanking the LED window so the lights stay
    visible. Engages over the last ~7 mm of insertion.
    [mount-right-1u.stl, mount.scad]
2026-08-09 Cage v4: test-print feedback round
    - eave_squeeze +0.2 -> -0.1: v1 print's friction fit was overly tight
    - mirror via right_half=true: unmirrored geometry is a left half
    - walls, eaves, brow all run flush to the panel top (print stability,
    fuller capture, cleans up the brow corner at the LED window)
    - outer wall no longer extends below the shelf
    - ONT rides on its rubber feet (Ø11 x 3, modeled in devices.scad):
    bay raised 3mm, solid landing pads in the hex field, bottom bosses
    hover; feet z-inset estimated pending calipers
    - LED window capped 2mm below the panel top edge
    [devices.scad, mount-right-1u.stl, mount.scad]
2026-08-09 Fix foot positions (chamfer-edge datum), add left-half brief
    Foot gaps are measured from the chamfer edge and apply on both axes
    from each corner. Seam groove verified 1mm deep via cross-section
    (the full-bisect appearance is an F5 preview artifact). 2U window
    enlargement noted. docs/left-half-brief.md hands the brick enclosure
    to a second instance.
    [devices.scad, mount.scad]
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2026-08-09 Model ONT rear-face ports (coax, fiber) as keep-out stubs
    Coax F center 36 from the -x face, green SC/APC plug outer edge 20
    from the +x face, both z-centered (calipers; stub sizes estimated).
    Fiber lands near the outer wall's rear exit gap as designed.
    [devices.scad, mount-left-2u.stl, mount-left.scad]
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2026-08-09 Right flange 6->8 for joint meat, document the M5/hex-nut interface
    Matches mount-left's 10-thick nut-pocket flange; M5x16 spans both.
    Bay shifts +2 in x; ear slot zone still clear.
    [mount-right-1u.stl, mount.scad]
2026-08-09 Left half v2: bay outboard, voron keystone recipe, joint ramp, wide slots
    Brick bay moves against the rack ear (cage stops 23 from the edge, the
    UCG mount's rack-proven margin) so the weight hangs by the mounting
    hardware; keystone swaps to the joint side at x=52, using the tuned
    slot recipe from ../voron-keystone-panel cut into a 7-thick rear boss.
    UCG-style gusset ramp braces the flange top edge. Ear ovals widen to
    14x7 for horizontal play; nut pockets tighten to 8.2 AF (UCG measures
    ~8.1, press-fits on this printer).
    [mount-left-2u.stl, mount-left.scad]
2026-08-09 Bay slightly inboard, floor under the cage only, twin inset joint ramps
    ear_clear 23->30; the shelf now spans just the cage width; the single
    top gusset becomes a pair, one near each panel edge, inset 6 in y.
    [mount-left-2u.stl, mount-left.scad]
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2026-08-09 Fillet the joint gussets, corner-rounding pass
    Gusset free edges become concave quarter-circle fillets (just over half
    the plastic of the straight triangles). Rounds: panel outer corners r4
    (keeps the ear-slot web), cage top-rear r8 in one cut across walls +
    eaves (eaves join the main union to be cut with them), flange rear
    corners r6 tangent to the inset ramps, shelf rear r6, keystone boss r3.
    [mount-left-2u.stl, mount-left.scad]
2026-08-09 Round cage outer edges, fifth hex column, slim the front bumper
    Wall top-outer and rear vertical edges round r2. Hex side margins 8->6
    fit a fifth column on alternating rows. The tab tip now rides to 2 from
    the panel front face — the slot pockets 2 into the panel's back — so
    the front wall drops from 12 to 9 thick and the whole depth chain pulls
    in 3 (body ends at z=137).
    [mount-left-2u.stl, mount-left.scad]
2026-08-09 Carry the edge round around the big corner round
    The straight r2 edge cutters stopped with a hard step where the r8
    top-rear round begins, leaving a proud band along the arc. They now
    terminate at the arc and a quarter-torus section (rotate_extrude of the
    same rounded cutter cross-section) sweeps the edge round along the r8
    curve. Wall silhouette verified against the ideal arc to within 0.02.
    [mount-left-2u.stl, mount-left.scad]
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2026-08-09 1U variant: brick pokes below the panel into the empty U beneath
    panel_u=1 drops the brick 2 below the panel bottom edge (floor + walls
    start behind the panel face so nothing shows from the front) and tops
    out ~2.4 under the neighbor panel — the UCG mount above keeps its rear
    structure 1.75 proud of its panel edge (measured from its STL), so real
    clearance is ~4. Keystone moves to x=60, gusset runout shortens to
    x=44; walls cap at the panel top; retention re-derives and fits.
    2U output verified identical (volume + bounds) after the refactor.
    [mount-left-1u.stl, mount-left-2u.stl, mount-left.scad]
2026-08-09 Keystone: UCG-style wedge slot, latch down
    Replace the voron flat-lip recipe with the slot measured off the UCG
    "Shelf Keystone x6" left module: teeth wedge against tapered clamp
    faces (self-tightening, no lip thickness to tune), 24.3 x 15.0 cavity,
    rear plate with a 19.8 insertion window guiding the jack, 9.5 boss.
    Latch side now faces DOWN (was up). Slot slices verified against the
    UCG STL: 17.59/24.3/19.8 vs 17.57/24.3/19.8.
    [mount-left-1u.stl, mount-left-2u.stl, mount-left.scad]
2026-08-09 Correct the brick model: real -x tab, drafted width (test-fit round)
    Calipers 2026-08-09: the -x mounting tab is 18.2 x 20.3, offset 24.4
    from the bottom face's -y edge (devices.scad had the +x tab's 11 x 12.5
    plan on both, centered). Body width is drafted, not 88: 83.4 at the
    bottom, 85.0 max at the mid-height seam, assumed 83.4 at the chamfer
    edge (TODO calipers). Bay narrows to 88 design (85 + 2x1.5), the tab
    slot re-derives from tabm_y, and the eaves drop by the chamfer-edge
    inset to keep the same engagement.
    [devices.scad, mount-left-1u.stl, mount-left-2u.stl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]
2026-08-09 Right piece: low ceiling — walls/eaves stop 3 past the eave slope
    wall_top was panel_h; the ~7 of full-thickness wall above the chamfer
    grab added no capture. Now eave-derived (eave_y + eave_depth + 3): the
    ONT's chamfered top stands ~2.8 proud of the outer wall. Flange stays
    full panel height for the joint; the brow is panel-face material and
    is untouched.
    [mount-right-1u.stl, mount.scad]
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2026-08-09 Revert "Right piece: low ceiling — walls/eaves stop 3 past the eave slope"
    This reverts commit 6e0254386b169defe4f25505c3082a94dda751a8.
    [mount-right-1u.stl, mount.scad]
2026-08-09 Brick cage: low eave-derived ceiling (the change 6e02543 meant to make)
    wall_top = eave_y + eave_depth + 3 — walls/eaves stop 3 past the eave
    slope, 47.8 at 2U (was 54), 39.8 at 1U. The brick's chamfered top
    stands ~2 proud. The brow's reach is now tied to the wall top (its 45°
    rise ends exactly at the wall-top corner, still spanning the full front
    chamfer face), which also removes the duplicate polygon vertex the cap
    would have created. Thinning brief's follow-up note updated: the right
    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
    [mount-left-1u.stl, mount-left-2u.stl, mount-left.scad]
2026-08-09 Hollow the brick cage: side-wall hex windows, windowed front wall
    Stage 1 of the material pass. Each side wall gets two elongated-hex
    windows (54 x 28.8 at 2U) with 45° pointed ends — the per-layer wall
    cross-section grows and closes at 45°, no flat bridges, just a ~6
    chord at each r4 tip — and an 8 rib between them. Rails tie to the
    existing lines: shelf_top + 4, eave_y - 3, front tips on the brick's
    face plane (body_z0), rear 8 matching the r8 corner round.
    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
    [mount-left-1u.stl, mount-left-2u.stl, mount-left.scad]
2026-08-09 ONT cage: brick-cage style — full walls, low ceiling, windows, insets
    Both side walls now run the full bay depth to the ONT's rear face (the
    inner one continues 4 thick past the flange) with full-length eaves;
    the rear stays fully open. Low eave-derived ceiling (wall_top = eave_y
    + eave_depth + 3; flange keeps panel height, brow is panel-face
    material). Wall hollowing ported from the brick cage: rounded
    elongated-hex windows — outer wall two, inner wall one behind the
    solid joint span, z-aligned. Joint hardware: M5x16 button heads inset
    Ø10.8 x 3 into the flange's bay-side face (head 9.5 x 2.75 vs 1.5 bay
    clearance), nuts stay in the left flange. Rounding vocabulary ported:
    panel corner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
    [mount-left.scad, mount-right-1u.stl, mount.scad]
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
